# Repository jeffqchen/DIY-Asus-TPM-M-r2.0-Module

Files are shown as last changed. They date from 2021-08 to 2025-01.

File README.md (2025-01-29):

# DIY ASUS TPM-M R2.0 Module

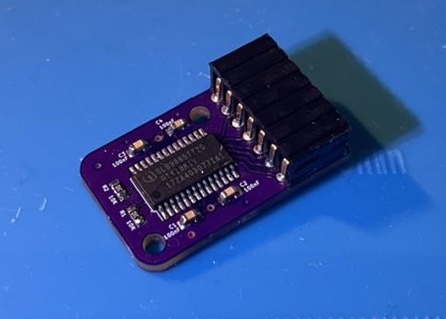
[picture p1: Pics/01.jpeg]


It's kinda hard to find those TPM modules that no one knew they needed - UNTIL Windows 11 happened. So here's one in case you need it.

There are many variants, so please use this as a reference to create your own.

--------

## Adapt to Asrock Motherboards



This module can also work on Asrock motherboards if you use [THIS](https://github.com/jeffqchen/DIY-Asus-TPM-M-r2.0-Module/tree/main/Asus%20To%20Asrock/KiCAD) adapter!

--------

## Parts

SLB9665TT20 TPM Chip:

-  https://www.ebay.com/itm/313526673758

2 mm pitch double row right angle pin header -   Choose the 2x7 option
-  https://www.aliexpress.com/item/32887332295.html

4x 100nF 6.3V 0603 SMD capacitors

2x 10K Ohm 0603 SMD resistors

PCB:
-   https://oshpark.com/shared_projects/pVqwq0NS

Note: You do NOT have to follow the links I used. The specs are pretty laid out so you can source your own parts if you prefer.

3D Printed Shell (Optional)
  - Print with the text facing upwards
  - Suggested layer height: 0.16mm.
  - Suggested line width: 0.35mm.
  - Uses two 6mm M2 screw and nut.
--------

## Assembly

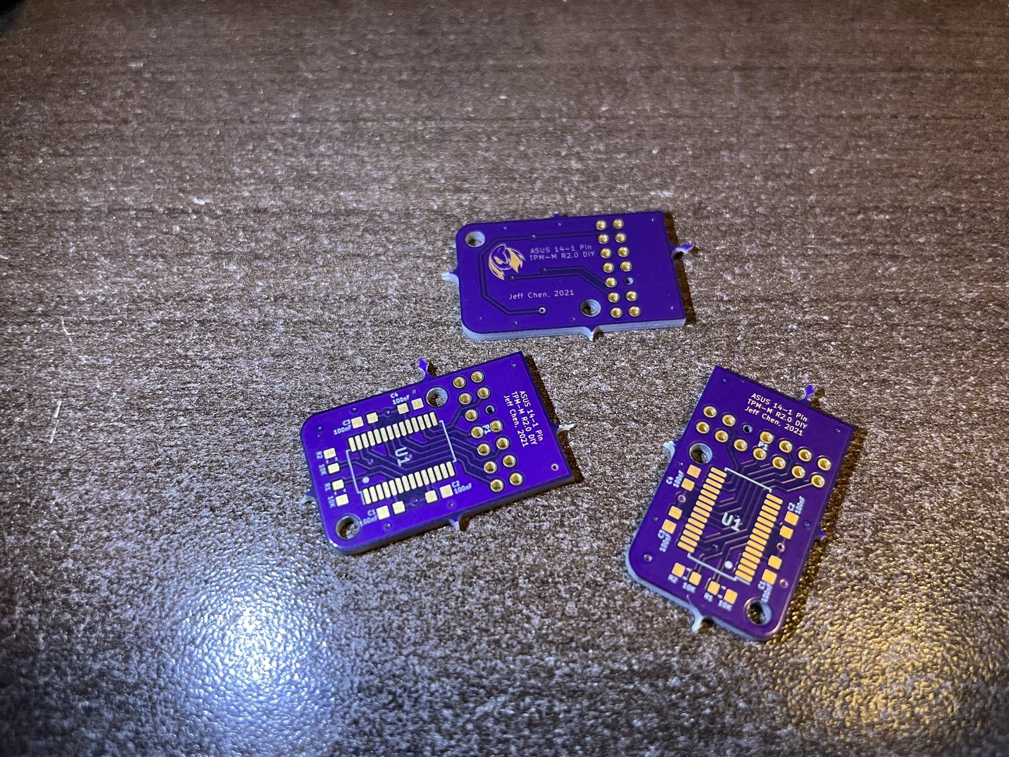
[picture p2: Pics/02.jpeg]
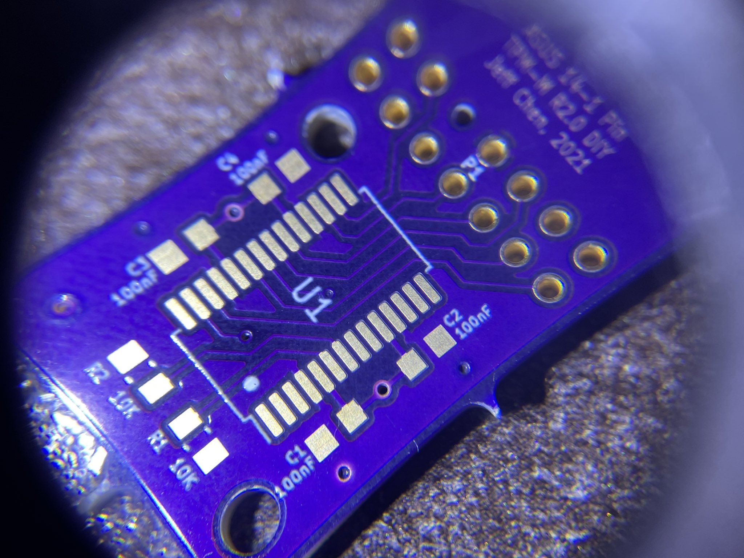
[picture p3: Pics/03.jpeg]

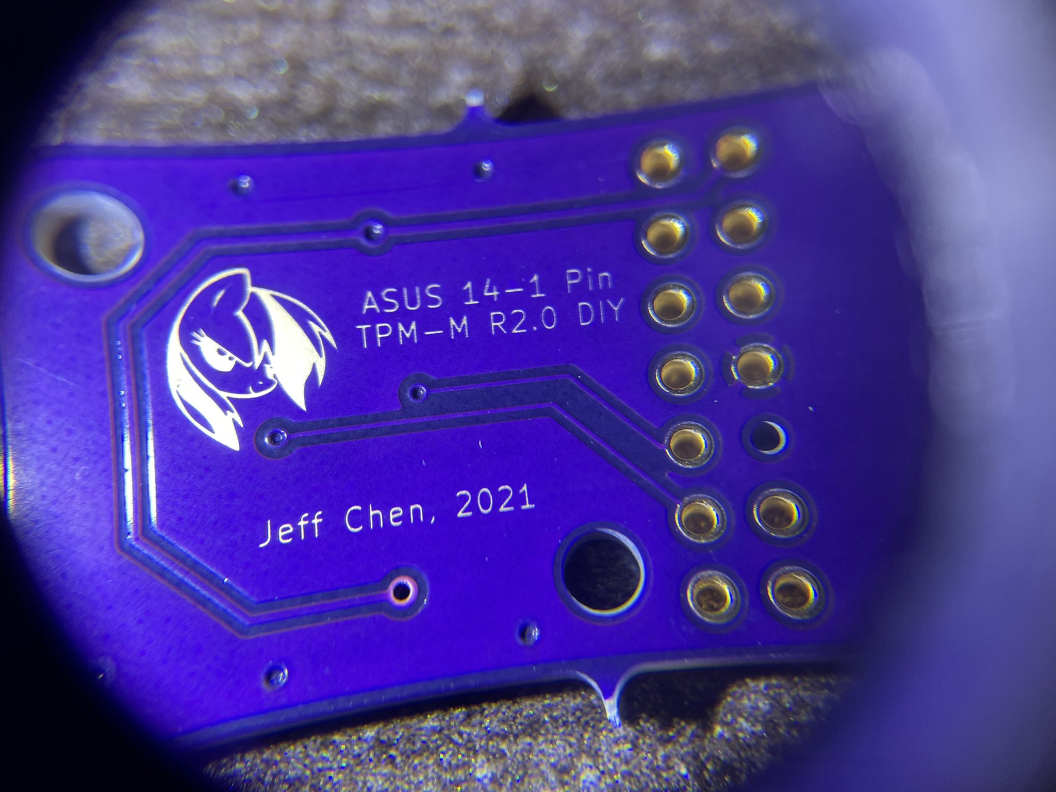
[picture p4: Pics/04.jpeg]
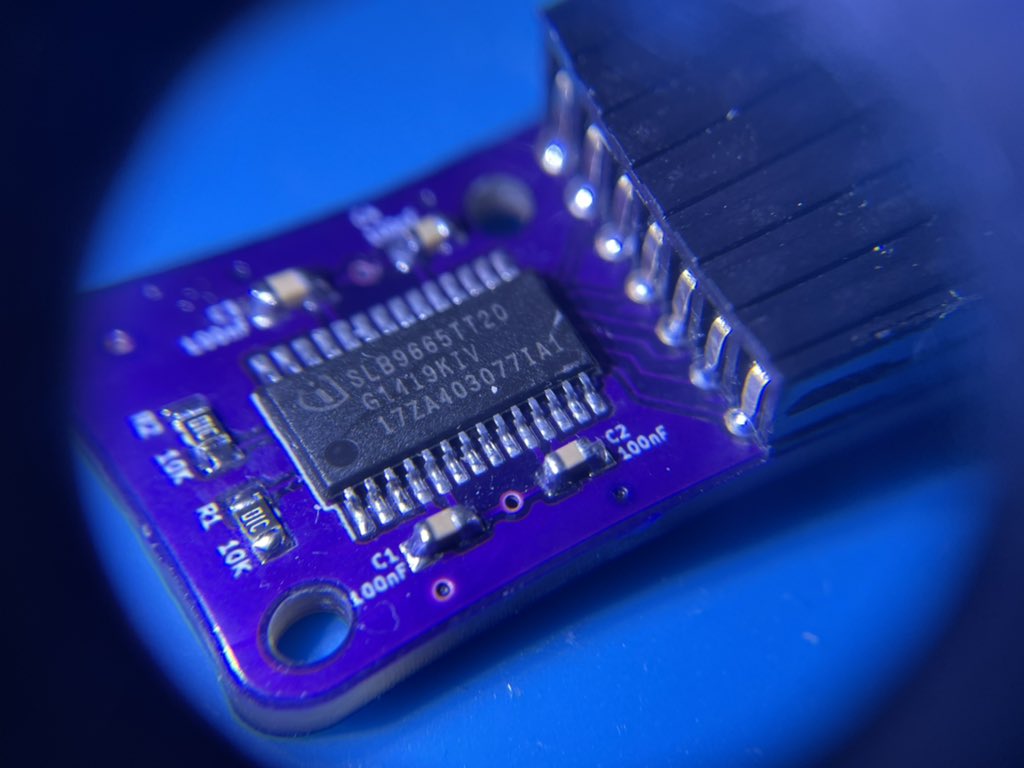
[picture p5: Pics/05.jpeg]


You have to know how to solder VERY well. Experience in soldering TSSOP and SMD components is required.

Note the pin header should be keyed. You can cut a piece of the compatible pin and stuff it into the hole on the bottom row, the 3rd one from the right.

Note: if you are an amateur on soldering, this might not be a bad project to learn how to solder, since everything is quite affordable. Learn how to pre-tin SMD pads for caps and resistor, how to tack a chip in place, and then drag solder alone one side, then the other. We all have to start from somewhere.

--------

## Installation

Jam it onto your motherboard with power turned OFF (I don't have to teach you the basics, right?) For my motherboard, once booted into the BIOS, the chip is automatically recognized and ready to go. Windows 10 also recognized it without any fuss.

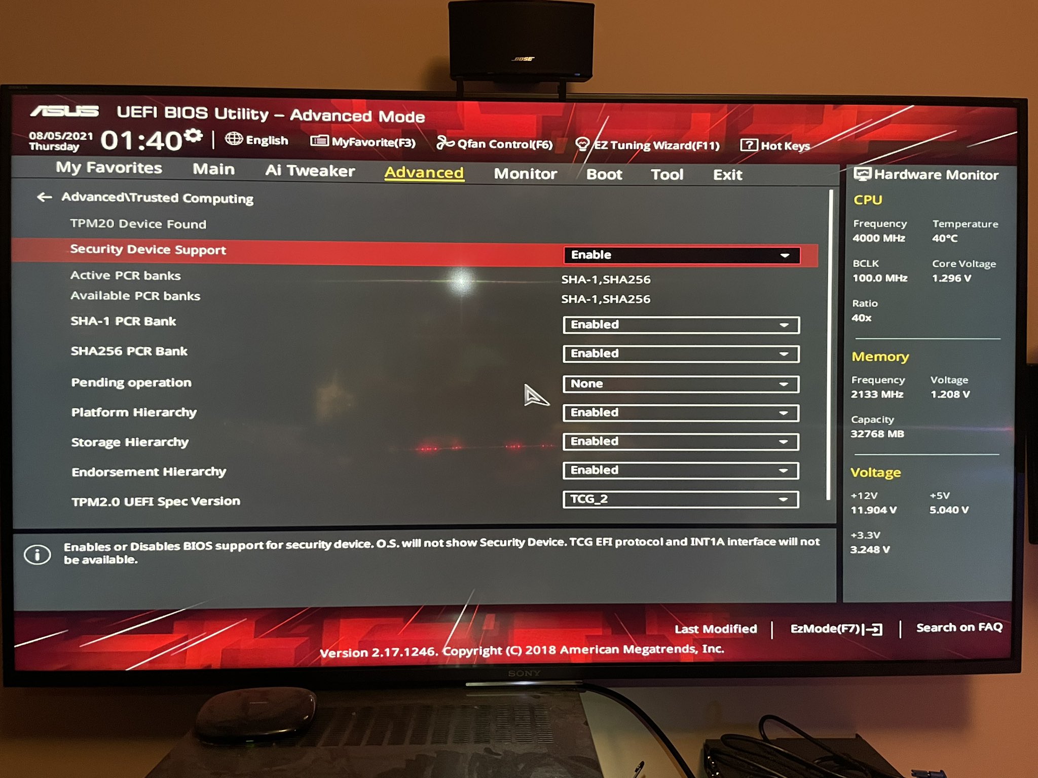
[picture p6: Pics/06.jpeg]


-------

## Updating TPM Chip Firmware

The firmware version on the chip might be quite out-dated and requires an update to work properly with Windows. Please refer to the following guides on how to update the firmware on your TPM chip:
- https://qzhou.dev/updating-a-vulnerable-tpm
- https://silvenga.com/upgrading-firmware-infineon-tpm/

Note: It is possible that your chips might come with a rare firmware version and no update could be found. You might have to find a different seller and try your luck if that's the case.

--------

## Reference

SLB9665TT20 Datasheet:
- https://www.infineon.com/dgdl/Infineon-data-sheet-SLB9665_2.0_Rev1.2-DS-v01_02-EN.pdf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

--------
Shield: [][cc-by-sa]

This work is licensed under a
[Creative Commons Attribution-ShareAlike 4.0 International License][cc-by-sa].

[][cc-by-sa]

[cc-by-sa]: http://creativecommons.org/licenses/by-sa/4.0/
[cc-by-sa-image]: https://licensebuttons.net/l/by-sa/4.0/88x31.png
[cc-by-sa-shield]: https://img.shields.io/badge/License-CC%20BY--SA%204.0-lightgrey.svg

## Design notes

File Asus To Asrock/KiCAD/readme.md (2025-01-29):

# Asus TPM 2.0 to Asrock TPM 2.0 Adapter



I created this adapter board so that I can use the module I created for Asus motherboards with Asrock motherboards. Yes, turns out they are compatible, just with the pins shuffled!

-------

# Parts

- 18-1 pin (2x9) pin header, female, 2.0mm pitched, right angle
- 14-1 pin (2x7) pin header, male 2.0mm pitched, right angle

-------

# Note



Remember to trim the missing pin on the male pin header for better anti-inverse measure!

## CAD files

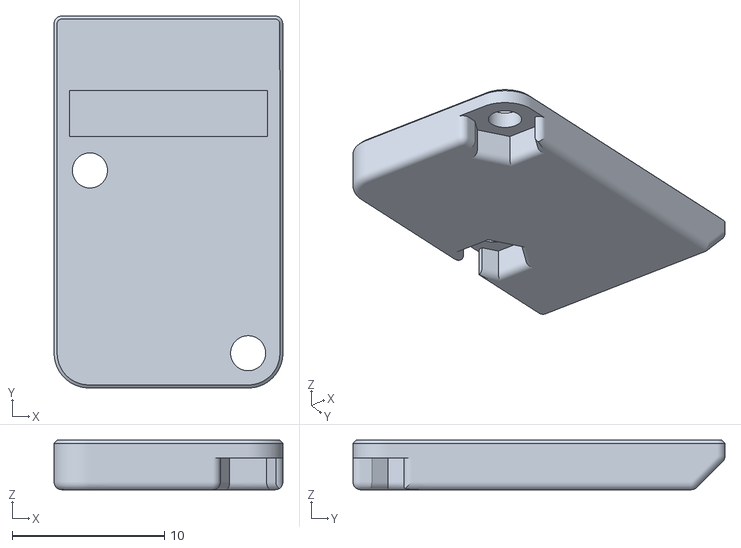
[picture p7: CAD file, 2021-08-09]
3D Print/Bottom_nologo.stl
15.0 x 24.4 x 3.25

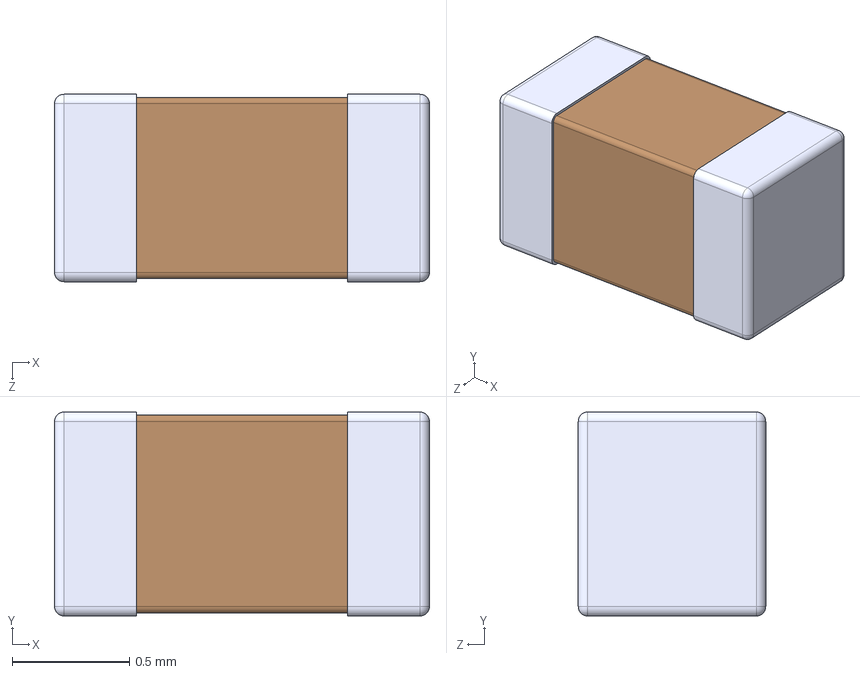
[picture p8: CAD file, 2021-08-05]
KiCAD/Files/C0603C180K4HAC7867/C0603C180K4HAC7867.step
1.60 x 0.87 x 0.8 mm

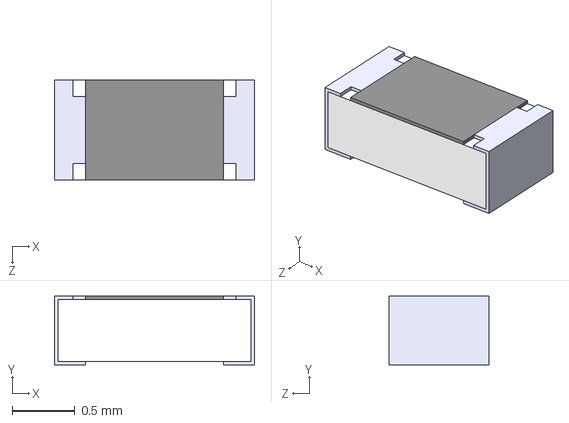
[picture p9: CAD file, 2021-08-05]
KiCAD/Files/RE0603FRE071KL/RE0603FRE071KL.step
1.60 x 0.55 x 0.8 mm

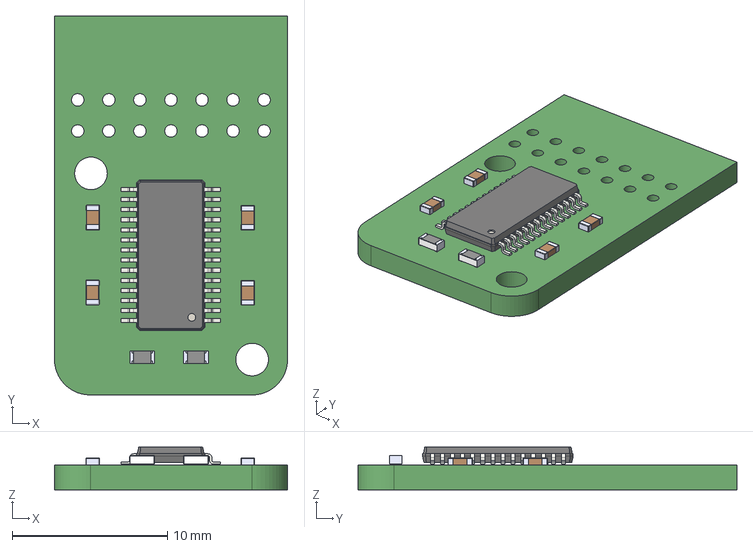
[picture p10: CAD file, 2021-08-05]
KiCAD/MyTPM.step
15.0 x 24.4 x 2.75 mm

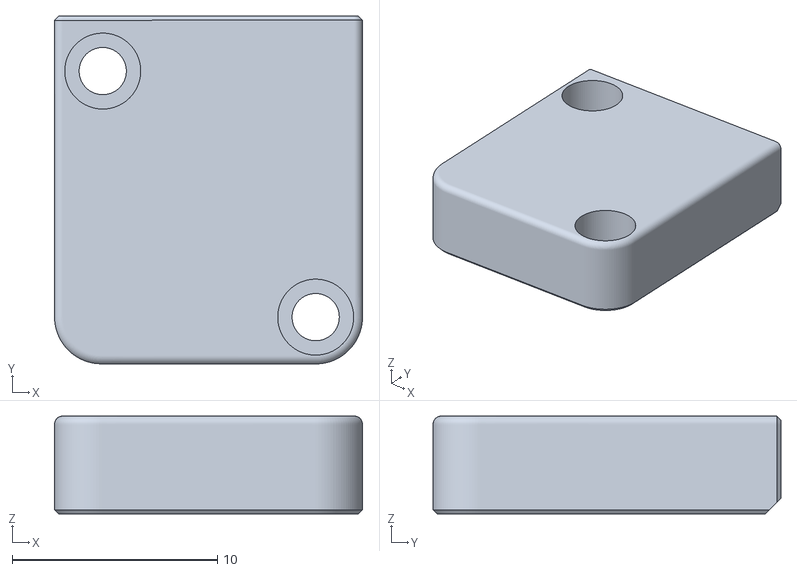
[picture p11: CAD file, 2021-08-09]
3D Print/Top_nologo.stl
15.0 x 17.0 x 4.77

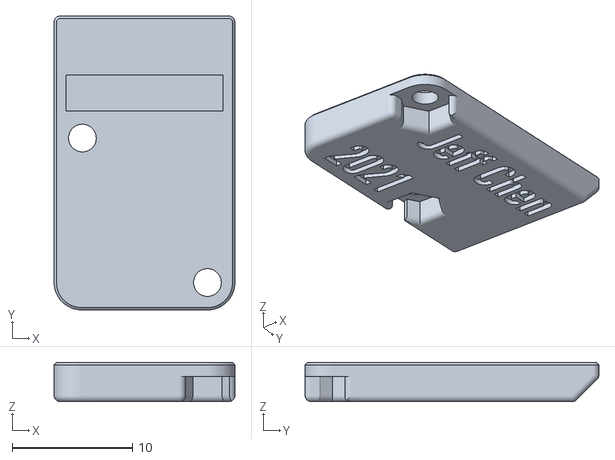
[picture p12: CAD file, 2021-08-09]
3D Print/Bottom.stl
15.0 x 24.4 x 3.25

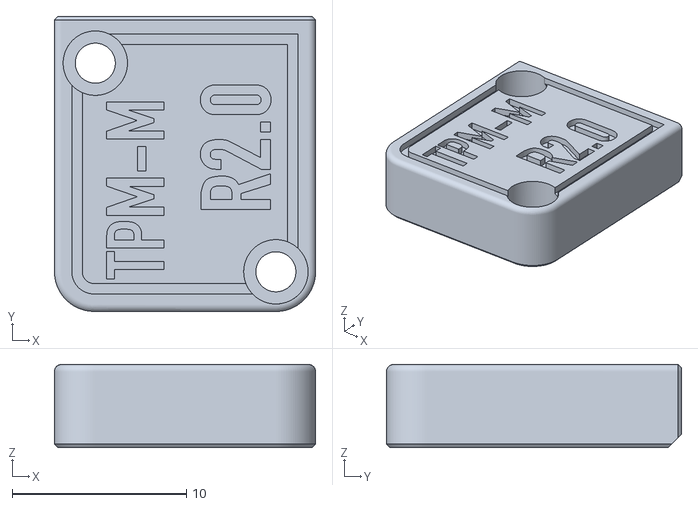
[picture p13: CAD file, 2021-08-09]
3D Print/Top.stl
15.0 x 17.0 x 4.77

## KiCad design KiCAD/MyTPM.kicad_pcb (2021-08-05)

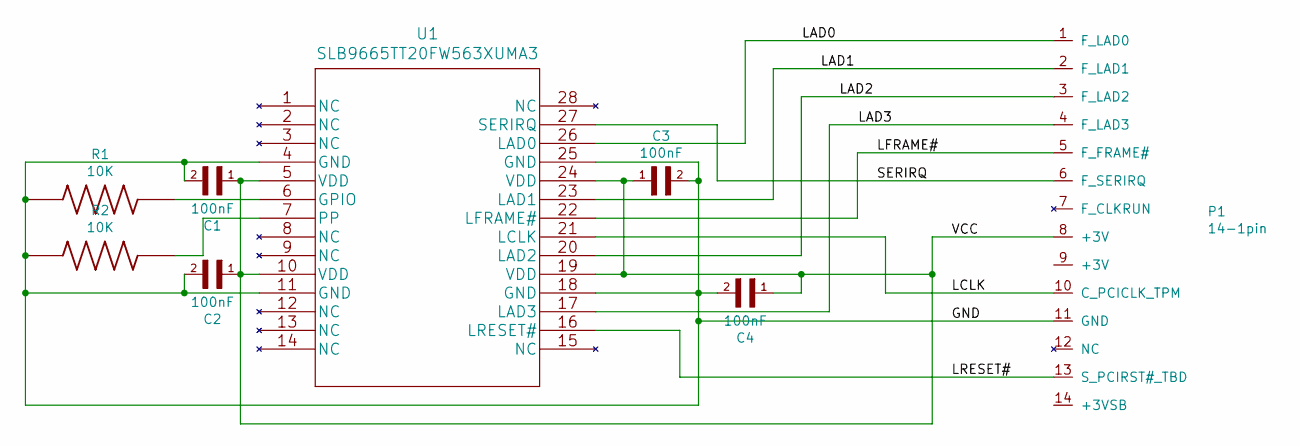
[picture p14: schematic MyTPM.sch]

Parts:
C1, C2, C3, C4: 100nF; CAPC1608X87N
P1: 14-1pin; 14-1Pin
R1, R2: 10K; RESC1608X55N
U1: SLB9665TT20FW563XUMA3; SLB9665TT20

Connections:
/GND: C1.2, C2.2, C3.2, C4.2, P1.11 (GND), R1.1, R2.1, U1.4 (GND), U1.11 (GND), U1.18 (GND), U1.25 (GND)
/LAD0: P1.1 (F_LAD0), U1.26 (LAD0)
/LAD1: P1.2 (F_LAD1), U1.23 (LAD1)
/LAD2: P1.3 (F_LAD2), U1.20 (LAD2)
/LAD3: P1.4 (F_LAD3), U1.17 (LAD3)
/LCLK: P1.10 (C_PCICLK_TPM), U1.21 (LCLK)
/LFRAME#: P1.5 (F_FRAME#), U1.22 (LFRAME#)
/LRESET#: P1.13 (S_PCIRST#_TBD), U1.16 (LRESET#)
/SERIRQ: P1.6 (F_SERIRQ), U1.27 (SERIRQ)
/VCC: C1.1, C2.1, C3.1, C4.1, P1.8 (+3V), U1.5 (VDD), U1.10 (VDD), U1.19 (VDD), U1.24 (VDD)
unnamed: R1.2, U1.6 (GPIO)
unnamed: R2.2, U1.7 (PP)

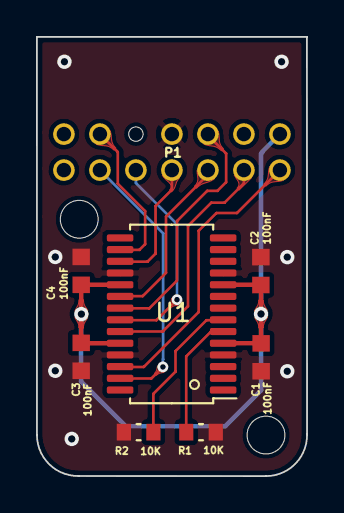
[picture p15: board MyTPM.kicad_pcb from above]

Board: 2 copper layers, 15.0 x 24.4 mm, 8 parts (1 on the bottom side), 12 nets.

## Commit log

2021-08-09 Add 3D print STL
    [Bottom.stl, C0603C180K4HAC7867.step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]
2021-08-09 Add logoless 3D print
    [Bottom_nologo.stl, Top_nologo.stl]
2024-12-01 Asus to Asrock Adapter
    [Asus To Asrock-B_Cu.gbr, Asus To Asrock-B_Mask.gbr, Asus To Asrock-B_Paste.gbr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]

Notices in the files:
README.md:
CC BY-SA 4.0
